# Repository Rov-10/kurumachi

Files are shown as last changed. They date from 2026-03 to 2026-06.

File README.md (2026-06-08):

<div align="center">

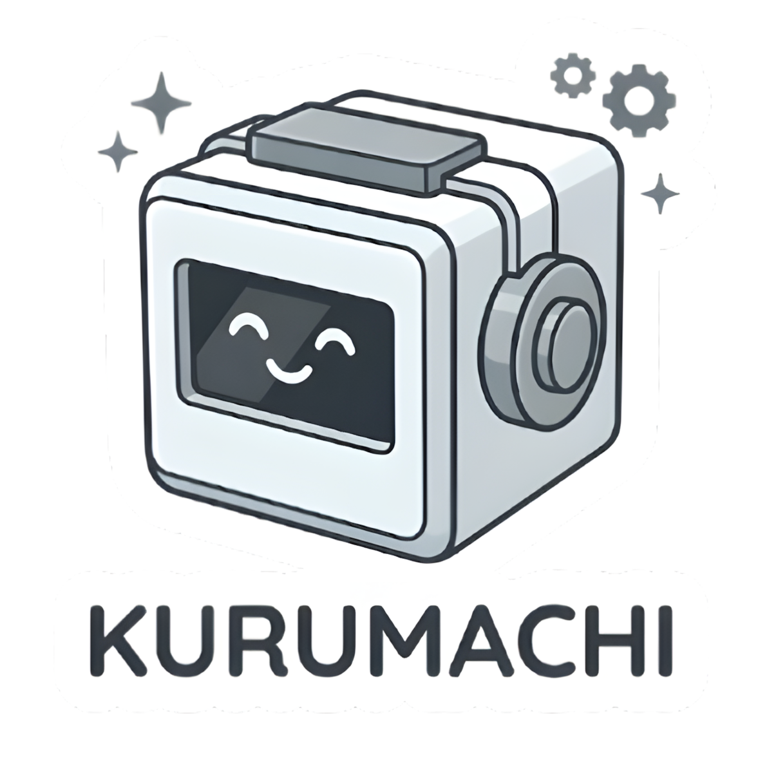
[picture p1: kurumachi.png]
Kurumachi


# kurumachi

**A tiny ESP32-C3 companion device — sensors, 44 animations, 3D-printed body, and a browser-based Web Suite.**






[Web Suite](#web-suite) · [Hardware](#hardware) · [Firmware](#firmware) · [Animations](#animations) · [Getting Started](#getting-started)

</div>

---

## What is this?

Kurumachi is an open-source ESP32-C3 companion that lives on your desk or dashboard. It reads the environment around it, reacts to tilt and motion via a built-in IMU, and plays one of **44 hand-crafted GIF animations** on a 1.3″ OLED — all packed inside a custom 3D-printed enclosure.

The project ships with a **full browser-based Web Suite** for flashing firmware, browsing CAD models, and converting your own GIFs to the on-device format — no native drivers required.

---

## Hardware

| Component | Part | Notes |
|---|---|---|
| MCU | ESP32-C3 Super Mini | RISC-V core, Wi-Fi + BLE |
| Display | SH1106 1.3″ OLED | I²C @ 400 kHz, 128×64 |
| IMU | BMI160 | 6-axis, roll/pitch tracking |
| Environment | AHT20 + BMP280 | Temp, humidity, pressure |
| Power | Li-Po 3.7V + TP4057 | ADC battery feedback |
| Input | Capacitive touch pad | Scene cycling |
| Audio | Passive buzzer | Tone sequences |

The enclosure is derived from the **Mochi** housing (MakerWorld) and distributed under **CC BY-NC-SA 4.0**. STL files and the full Blender source are in `firmware/web/public/kurumachi/`.

---

## Firmware

Written in C++ with PlatformIO. Source lives in `firmware/kurumachi/src/`.

```
src/
├── main.cpp          — ISR loop and serial command parser
├── animation.h       — XBM frame decoder and playback engine
├── animations_list.h — Animation registry (44 entries)
├── bmi160.h          — IMU tilt tracking
├── battery.h         — ADC voltage → percentage
├── scenes.h          — Scene state machine
├── display.h         — SH1106 driver wrapper
├── buzzer.h          — Tone sequencer
├── button.h          — Touch input debouncing
├── sleep.h           — Deep sleep management
└── config.h          — Pin map and constants
```

Animations are stored as **inverted XBM C headers** in PROGMEM, converted from GIF source files using `tools/gif2header.py`.

---

## Animations

44 animations across five categories, each a GIF converted to an XBM frame array:

| Category | Animations |
|---|---|
| **Actions** | eat · pingpong · sleepy · sneeze × 2 · speed · water gun × 2 · yawn |
| **Emotions** | angry × 4 · devil · distracted · dizzy · frustrated · happy · love × 2 · proud · relaxed · scared · smile · smirk · surprised · uwu |
| **Eyes** | look left · look right · peek · squint · wink |
| **Effects** | rotate · sakura · shrink |
| **System / Theme** | idle · scx · bee · dragon · nose fire · hello · MD · slayer · cry |

To add your own:

```bash
python tools/gif2header.py your_animation.gif
# outputs your_animation.h → place in firmware/kurumachi/assets/animations/
# register it in src/animations_list.h
```

---

## Web Suite

Built with **Next.js 15** + TypeScript. Run locally or deploy to Vercel.

```
web/src/
├── app/
│   ├── page.tsx          — Landing page with 3D model viewer
│   ├── docs/             — Hardware docs (BOM, wiring, print specs)
│   ├── installer/        — Browser-based firmware flasher
│   └── tools/            — RLE encoder utility
└── components/
    ├── ThreeViewer.tsx    — WebGL CAD inspector (Three.js)
    ├── AnimationsShowcase.tsx
    ├── Configurator.tsx
    └── installer/
        ├── FlasherBlock.tsx   — Web Serial flash pipeline
        └── ConfiguratorBlock.tsx
```

### Features

**Web Serial Flasher** — Flash firmware directly from Chrome/Edge over USB. No drivers. No CLI.

**3D Model Inspector** — Browse every printed part in WebGL, inspect assembly, download individual STLs or the full ZIP.

**RLE Encoder** — Drop a PNG/BMP into the browser, get a ready-to-paste C header using the device's compression format: `((run_length - 1) << 1) | pixel_state`.

**Docs** — Interactive BOM, wiring diagram, and print specifications.

---

## Getting Started

### Firmware

```bash
git clone https://github.com/Rov-10/kurumachi
cd kurumachi/firmware/kurumachi
pio run --target upload
```

Requires [PlatformIO Core](https://docs.platformio.org/en/latest/core/installation.html).

### Web Suite

```bash
cd firmware/web
npm install
npm run dev
```

Open `http://localhost:3000`. Chrome or Edge required for Web Serial.

---

## Repository Layout

```
kurumachi/
├── firmware/
│   ├── kurumachi/          — ESP32 firmware (PlatformIO)
│   │   ├── assets/
│   │   │   ├── animations/ — 44 XBM C headers
│   │   │   └── gifs/       — Source GIFs
│   │   └── src/            — Firmware source
│   └── web/                — Next.js Web Suite
├── tools/
│   └── gif2header.py       — GIF → XBM converter
├── kurumachi.png
└── README.md
```

## KURUMACHI. ECOSYSTEM ROADMAP

STAGE 1: CORE INFRASTRUCTURE [COMPLETED]
- Web Deployment Suite architecture implementation (Next.js 15).
- Web Serial API driverless integration for ESP32-C3 USART pipelines.
- WebGL-driven 3D CAD asset inspector using HTML5 Canvas & Three.js.
- Client-side mathematical RLE encoder engine.

STAGE 2: FIRMWARE OPTIMIZATION & CUSTOM ASSETS [IN PROGRESS]
- Hardware debug and stability verification of the RISC-V C++ framework.
- Implementation of dynamic client-to-node animation buffering.
- Development of runtime custom RLE stream loading over Wi-Fi (WebSockets/HTTP Server).
- Tilt/Roll active correction routines based on 6-Axis BMI160 IMU registers.

STAGE 3: THE DIPLOMA EXTENSION (AUTOMOTIVE & MOBILE HARNESS)
- Development of a cross-platform mobile app using Dart & Flutter.
- Automotive integration via Skoda Fabia Mk1 CAN-Bus / K-Line hardware sniffing.
- Bluetooth Low Energy (BLE) secure authentication and telemetry logging.
- Low-power Deep Sleep automation coupled with vehicle ignition state triggers.

---

## License

| Layer | License |
|---|---|
| Firmware & Web Suite | [MIT](LICENSE) |
| Hardware enclosure | [CC BY-NC-SA 4.0](https://creativecommons.org/licenses/by-nc-sa/4.0/) — derived from Mochi (MakerWorld) |

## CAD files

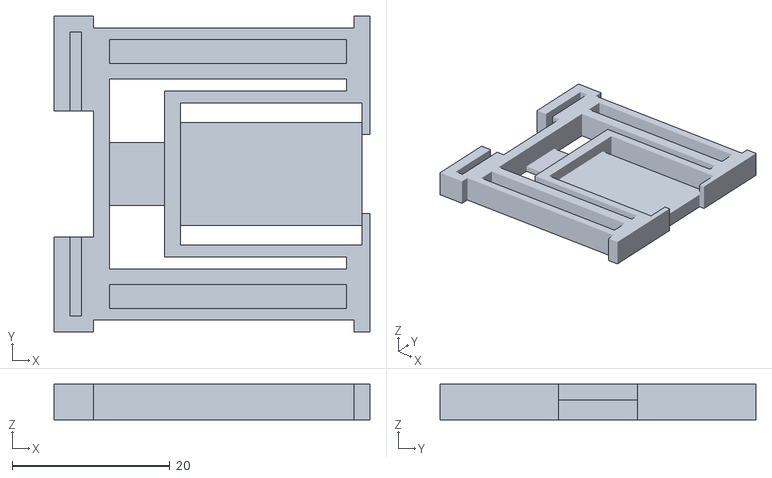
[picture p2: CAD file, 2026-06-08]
firmware/web/public/kurumachi/Large OLED Bottom-Body.stl
40.0 x 40.0 x 4.50

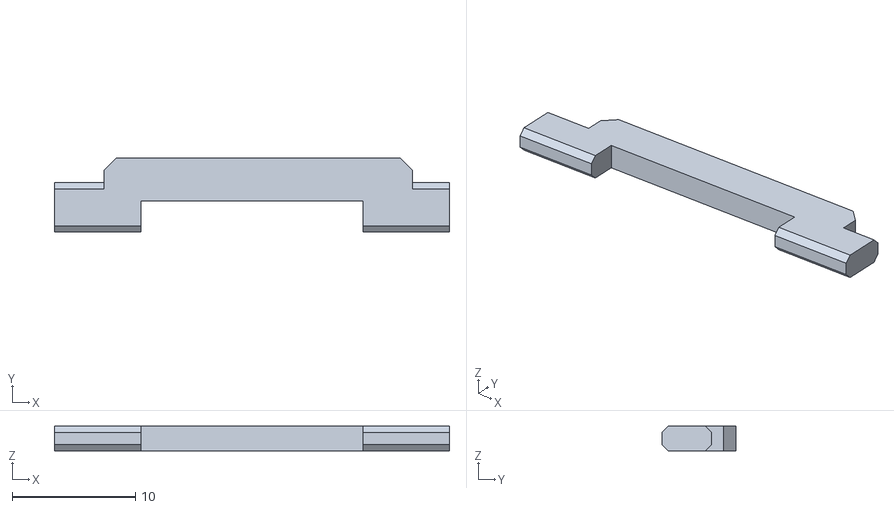
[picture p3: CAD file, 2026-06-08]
firmware/web/public/kurumachi/ESP32 Holder Front-Body.stl
32.0 x 6.00 x 2.00

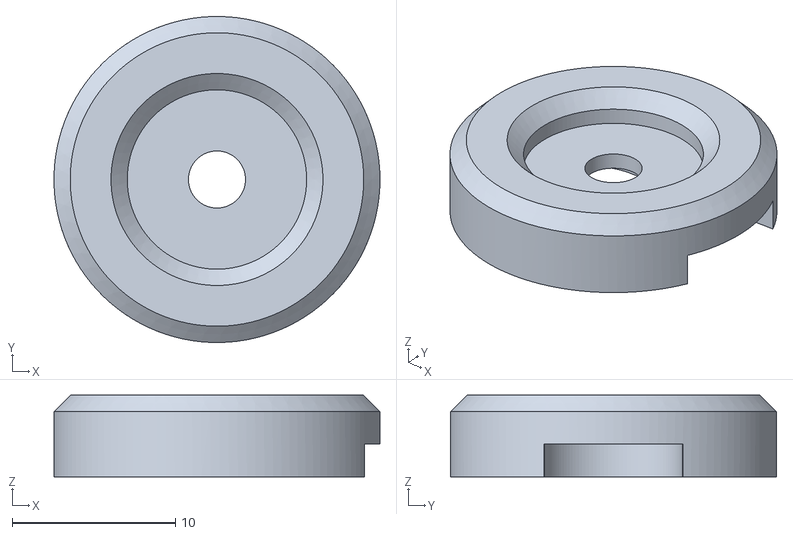
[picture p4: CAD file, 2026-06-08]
firmware/web/public/kurumachi/Ear Headphone Cup Driver v2-Body.stl
20.0 x 20.0 x 5.00

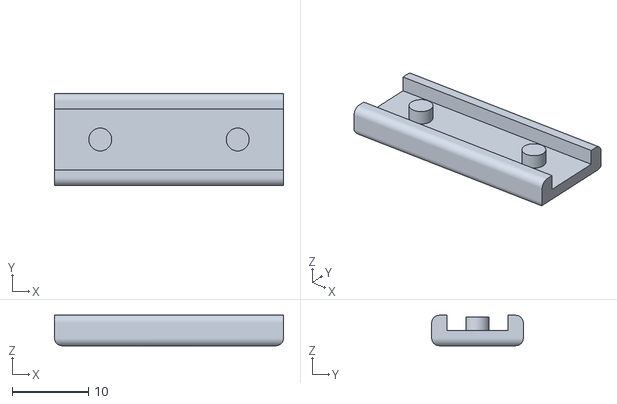
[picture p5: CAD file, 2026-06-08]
firmware/web/public/kurumachi/Ear Headphone Headband-Body.stl
30.0 x 12.0 x 4.00

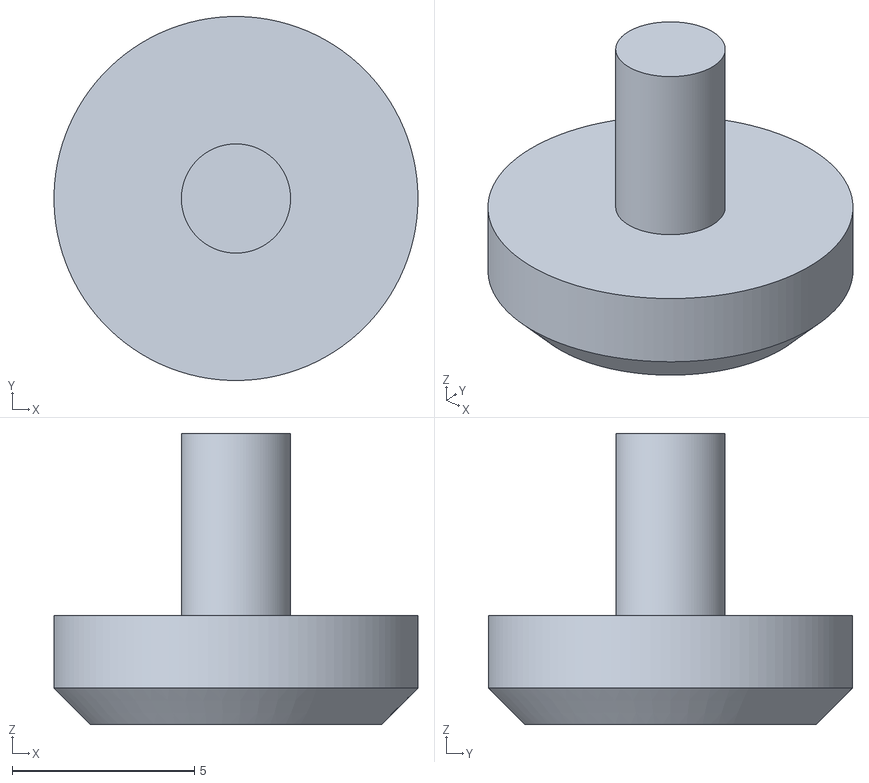
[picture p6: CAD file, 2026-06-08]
firmware/web/public/kurumachi/Ear Headphone Driver v2-Body.stl
10.00 x 10.00 x 8.00

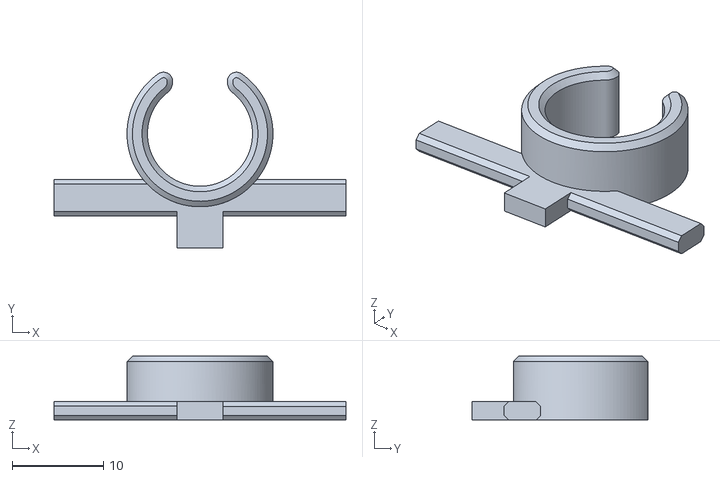
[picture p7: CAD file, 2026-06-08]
firmware/web/public/kurumachi/Touch Holder-Body.stl
32.0 x 19.2 x 7.00

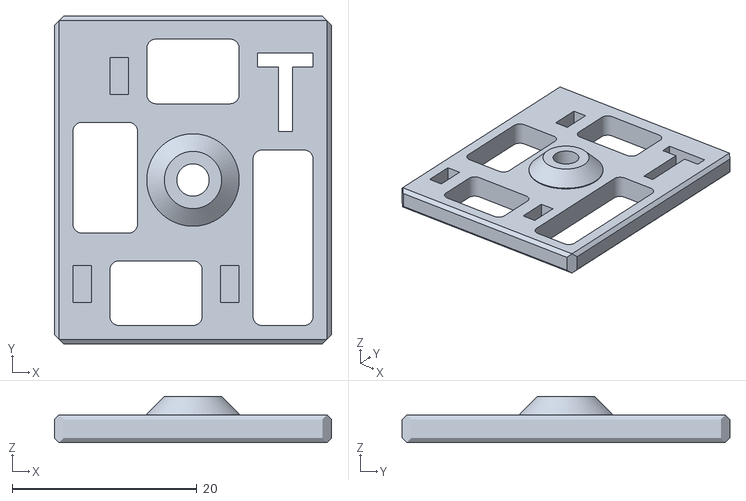
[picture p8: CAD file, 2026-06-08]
firmware/web/public/kurumachi/Vertical Base Right.stl
30.0 x 35.5 x 5.00

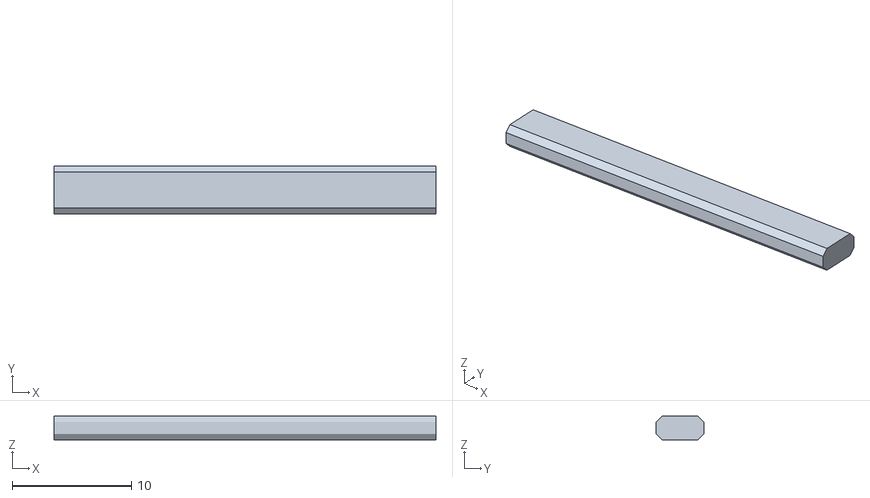
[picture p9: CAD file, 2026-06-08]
firmware/web/public/kurumachi/ESP32 Holder Rear-Body.stl
32.0 x 4.00 x 2.00

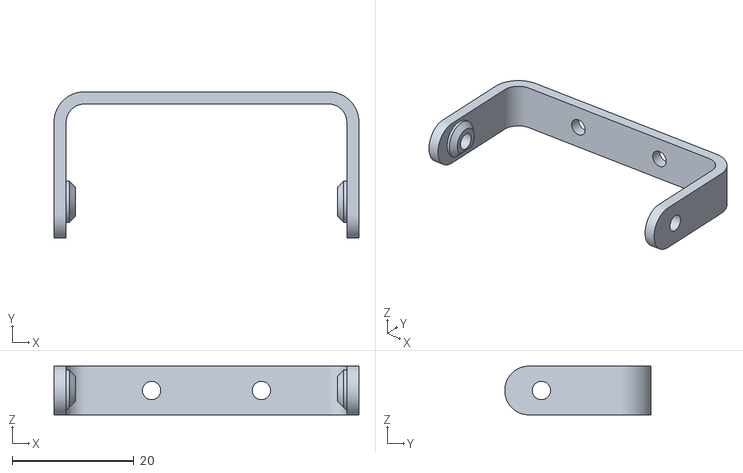
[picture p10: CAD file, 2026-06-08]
firmware/web/public/kurumachi/Ear Headphone 1-Body.stl
50.0 x 24.0 x 8.00

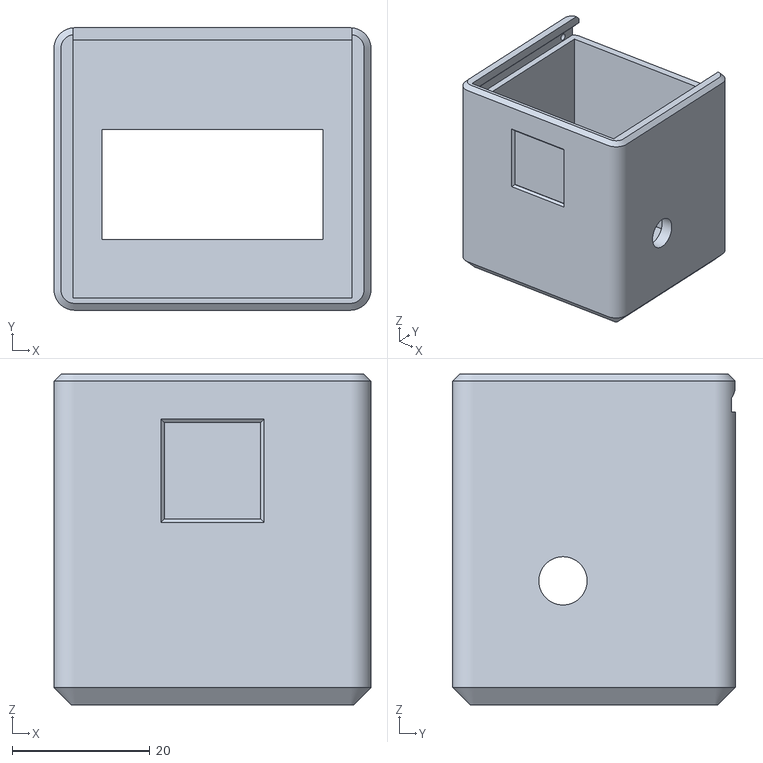
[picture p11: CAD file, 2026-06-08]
firmware/web/public/kurumachi/Housing-Body.stl
46.0 x 41.0 x 48.0

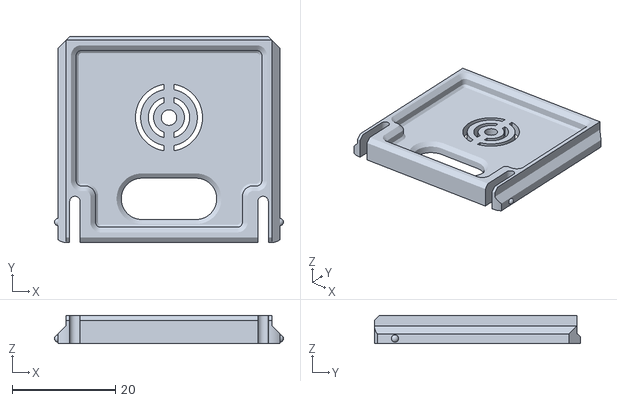
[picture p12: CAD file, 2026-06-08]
firmware/web/public/kurumachi/Back Plate-Body.stl
44.4 x 40.0 x 5.50

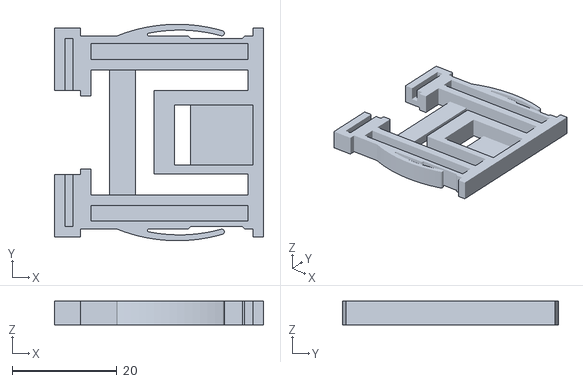
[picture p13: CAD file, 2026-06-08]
firmware/web/public/kurumachi/Large OLED Top-Body.stl
40.0 x 41.4 x 4.50

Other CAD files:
firmware/web/public/kurumachi/Vertical Base Left.stl
firmware/web/public/kurumachi/kurumachi_set.blend

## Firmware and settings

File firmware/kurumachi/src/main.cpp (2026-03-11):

#include "config.h"
#include "bmi160.h"
#include "battery.h"
#include "buzzer.h"
#include "sleep.h"
#include "bitmaps.h"
#include "display.h"
#include "scenes.h"        // включає animations_list.h → animation.h
#include "button.h"        // після scenes.h бо використовує animSceneInit()

// ── Визначення глобальних змінних ────────────────────────────────────────────
U8G2_SH1106_128X64_NONAME_F_HW_I2C u8g2(U8G2_R0, U8X8_PIN_NONE);
Adafruit_AHTX0  aht;
Adafruit_BMP280 bmp;
uint8_t currentScene = 0;
bool    bmiOk = false, ahtOk = false, bmpOk = false;
bool    sleeping = false;
float ax = 0, ay = 0, az = 0, gx = 0, gy = 0, gz = 0;
float temperature = 0, humidity = 0, pressure = 0;
unsigned long lastSensorRead = 0, lastMotionTime = 0;
int16_t prev_ax = 0, prev_ay = 0, prev_az = 0;
float rollOffset = 0.0f, pitchOffset = 0.0f;
unsigned long lastTapTime    = 0;
unsigned long pressStartTime = 0;
uint8_t       tapCount       = 0;
bool          wasPressed     = false;
bool          holdFired      = false;

// ── Setup ────────────────────────────────────────────────────────────────────
void setup() {
  Serial.begin(115200);
  delay(500);
  pinMode(PIN_TOUCH, INPUT);
  pinMode(PIN_BUZZER, OUTPUT);
  Wire.begin(PIN_SDA, PIN_SCL);
  Wire.setClock(400000);
  delay(100);
  u8g2.begin();
  u8g2.clearBuffer();
  u8g2.setFont(u8g2_font_6x10_tf);
  u8g2.drawStr(0, 20, "Initializing...");
  u8g2.sendBuffer();
  delay(300);
  bmiOk = bmi160Init();
  ahtOk = aht.begin();
  bmpOk = bmp.begin(0x77);
  if (bmpOk) bmp.setSampling(Adafruit_BMP280::MODE_NORMAL,
                              Adafruit_BMP280::SAMPLING_X2,
                              Adafruit_BMP280::SAMPLING_X16,
                              Adafruit_BMP280::FILTER_X16,
                              Adafruit_BMP280::STANDBY_MS_500);
  bmi160ReadRawAccel(prev_ax, prev_ay, prev_az);
  lastMotionTime = millis();
  Serial.printf("BMI:%d AHT:%d BMP:%d\n", bmiOk, ahtOk, bmpOk);
  drawStatusScreen();
  delay(1500);
  startupBeep();
  animSceneInit();
}

// ── Loop ─────────────────────────────────────────────────────────────────────
void loop() {
  unsigned long now = millis();
  if (sleeping) {
    sleepTick();
    if (bmiOk && checkMotion()) wakeUp();
    return;
  }
  handleButton();
  if (now - lastSensorRead >= 500) {
    lastSensorRead = now;
    if (bmiOk) {
      bmi160ReadData(ax, ay, az, gx, gy, gz);
      if (checkMotion()) lastMotionTime = now;
    }
    if (ahtOk) {
      sensors_event_t h, t;
      aht.getEvent(&h, &t);
      temperature = t.temperature;
      humidity    = h.relative_humidity;
    }
    if (bmpOk) pressure = bmp.readPressure() / 100.0f;
    Serial.printf("T:%.1f H:%.1f P:%.1f | AX:%.2f AY:%.2f AZ:%.2f\n",
                  temperature, humidity, pressure, ax, ay, az);
  }
  if (now - lastMotionTime >= SLEEP_TIMEOUT_MS) {
    enterSleepMode();
    return;
  }
  switch (currentScene) {
    case 0: drawScene0(); break;   // Анімації
    case 1: drawScene1(); break;   // Clock
    case 2: drawScene2(); break;   // IMU
    case 3: drawScene3(); break;   // ENV
    case 4: drawScene4(); break;   // Tilt
  }
}

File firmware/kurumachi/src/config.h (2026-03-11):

#pragma once

#include <Wire.h>
#include <math.h>
#include <U8g2lib.h>
#include <Adafruit_AHTX0.h>
#include <Adafruit_BMP280.h>
#include "esp_sleep.h"

// ── Піни ─────────────────────────────────────────────────────────────────────
#define PIN_TOUCH   4
#define PIN_BUZZER  1
#define PIN_SDA     8
#define PIN_SCL     9
#define PIN_VBAT    3

// ── Адреси ───────────────────────────────────────────────────────────────────
#define BMI160_ADDR 0x68

// ── Налаштування ─────────────────────────────────────────────────────────────
#define MOTION_THRESHOLD  800
#define SLEEP_TIMEOUT_MS  (2UL * 60 * 1000)
#define SLEEP_CHECK_US    (500UL * 1000)
#define VBAT_CALIBRATION  0.917f
#define DOUBLE_TAP_MS     400
#define HOLD_MS           1000

// ── Глобальні об'єкти ────────────────────────────────────────────────────────
extern U8G2_SH1106_128X64_NONAME_F_HW_I2C u8g2;
extern Adafruit_AHTX0  aht;
extern Adafruit_BMP280 bmp;

// ── Стан пристрою ────────────────────────────────────────────────────────────
extern uint8_t currentScene;
extern bool    bmiOk, ahtOk, bmpOk;
extern bool    sleeping;

extern float ax, ay, az, gx, gy, gz;
extern float temperature, humidity, pressure;

extern unsigned long lastSensorRead, lastMotionTime;
extern int16_t prev_ax, prev_ay, prev_az;

extern float rollOffset, pitchOffset;

// ── Стан кнопки ──────────────────────────────────────────────────────────────
extern unsigned long lastTapTime;
extern unsigned long pressStartTime;
extern uint8_t       tapCount;
extern bool          wasPressed;
extern bool          holdFired;

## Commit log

2026-03-11 Enhance animation handling and scene management
    - Updated platformio.ini to configure flash size and partitions for ESP32-C3.
    - Increased scene count to 5 in button.h, allowing for additional animations.
    - Refactored main.cpp to initialize animations and handle new scene logic.
    - Improved scenes.h to include detailed comments and manage animation states.
    - Introduced animation.h for defining animation structures and handling RLE decoding.
    - Added animations_list.h to manage multiple animations and random selection logic.
    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
2026-06-07 feat: add Shiki code landing showcase section
2026-06-07 feat: implement 2.5D spatial parallax viewer for main device logo
2026-06-08 refactor: complete atomic декомпозицію home page and extract HeroSection component
2026-06-08 style: replace DotGothic16 with Silkscreen for geometric lowercase and uppercase letter alignment
2026-06-08 fix: enforce strict model exposure override on component mount to prevent lighting reset
2026-06-08 feat: build full interactive 3D Docs tab system including BOM, pinout maps, and slicing specs
2026-06-08 style: increase global font scales for internal routes and navbar items for better readability
    [Back Plate-Body.stl, ESP32 Holder Front-Body.stl, ESP32 Holder Rear-Body.stl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]
2026-06-08 Add KURUMACHI Ecosystem Roadmap to README
    Added KURUMACHI Ecosystem Roadmap detailing project stages and tasks.

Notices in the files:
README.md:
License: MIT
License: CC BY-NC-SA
